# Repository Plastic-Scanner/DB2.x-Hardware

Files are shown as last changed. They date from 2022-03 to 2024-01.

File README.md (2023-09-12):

# DB2.x-Hardware

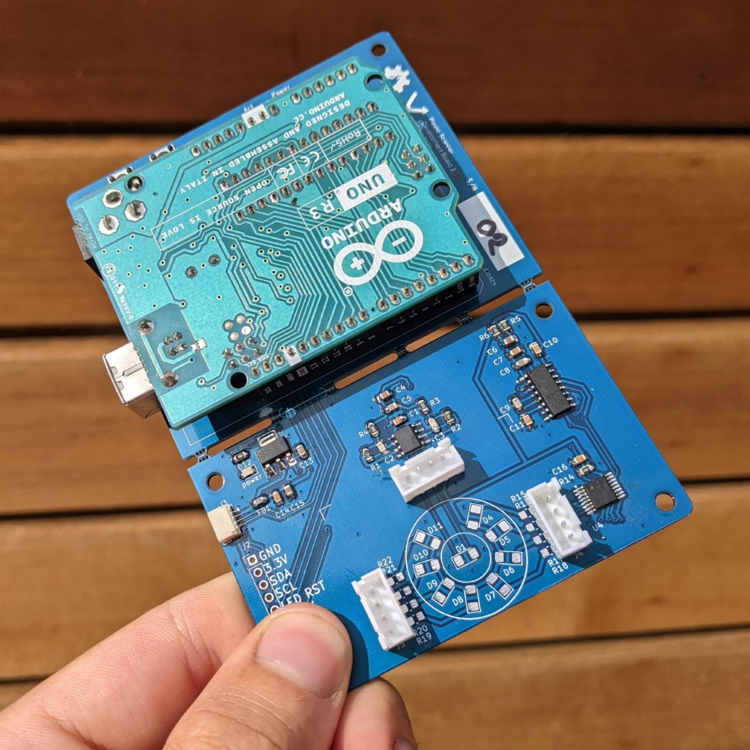
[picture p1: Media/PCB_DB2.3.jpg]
development board 2.3


>CAUTION  
This is still an early development prototype. We recommend all makers, hackers and contributors to wait until the next development board release, where we will focus on making it reproducible and invite everyone to collaborate on.  

Hi and welcome to the hardware package of the Development Board 2.x
this repository is meant to host files and have releases. 

Learn more about the development board by visiting our [documentation page](https://docs.plasticscanner.com/boards/DB2.2).  
<!-- Find the firmware for the development board [here](https://github.com/Plastic-Scanner/DB2.x-Firmware) -->

license

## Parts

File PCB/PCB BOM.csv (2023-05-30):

Id | Designator | Footprint | Quantity | Designation | Supplier and ref
1 | D5 | LED_1206_3216Metric_Pad1.42x1.75mm_HandSolder | 1 | 1050nm
2 | mouse-bite-2mm-slot,mouse-bite-2mm-slot,mouse-bite-2mm-slot,mouse-bite-2mm-slot,mouse-bite-2mm-slot,mouse-bite-2mm-slot | mouse-bite-2mm-slot | 6 | VAL**
3 | D12,D3 | LED_0805_2012Metric_Pad1.15x1.40mm_HandSolder | 2 | LED RED
4 | R15,R17,R21,R16,R19,R20,R22,R18 | R_0805_2012Metric_Pad1.20x1.40mm_HandSolder | 8 | 47
5 | D1 | D_1206_3216Metric_Pad1.42x1.75mm_HandSolder | 1 | 0090-3111-185
6 | R6,R5 | R_0805_2012Metric_Pad1.20x1.40mm_HandSolder | 2 | 51
7 | R9,R10 | R_0805_2012Metric_Pad1.20x1.40mm_HandSolder | 2 | 10k
8 | J3 | JST_SH_SM04B-SRSS-TB_1x04-1MP_P1.00mm_Horizontal | 1 | Qwiic
9 | C5,C8 | C_0805_2012Metric_Pad1.18x1.45mm_HandSolder | 2 | 100p
10 | D10 | LED_1206_3216Metric_Pad1.42x1.75mm_HandSolder | 1 | 1650nm
11 | U1 | SOIC127P599X175-8N | 1 | OPA2376AID
12 | C13 | C_0805_2012Metric_Pad1.18x1.45mm_HandSolder | 1 | 10u
13 | C10,C7,C1,C11 | C_0805_2012Metric_Pad1.18x1.45mm_HandSolder | 4 | 0.1u
14 | D9 | LED_1206_3216Metric_Pad1.42x1.75mm_HandSolder | 1 | 1550nm
15 | U2 | Nuvoton-NAU7802SGI-0-0-0 | 1 | NAU7802SGI
16 | C4 | C_0805_2012Metric_Pad1.18x1.45mm_HandSolder | 1 | 47n
17 | A1 | Arduino_UNO_R3 | 1 | Arduino_UNO_R3
18 | C16,C14 | C_0805_2012Metric_Pad1.18x1.45mm_HandSolder | 2 | 100n
19 | C6,C15 | C_0805_2012Metric_Pad1.18x1.45mm_HandSolder | 2 | 22u
20 | R4,R3 | R_0805_2012Metric_Pad1.20x1.40mm_HandSolder | 2 | 300
21 | R2,R1 | R_0805_2012Metric_Pad1.20x1.40mm_HandSolder | 2 | 240k
22 | FB1 | R_0805_2012Metric_Pad1.20x1.40mm_HandSolder | 1 | FerriteBead
23 | C9 | C_0805_2012Metric_Pad1.18x1.45mm_HandSolder | 1 | 330p
24 | D6 | LED_1206_3216Metric_Pad1.42x1.75mm_HandSolder | 1 | 1200nm
25 | J5,J1,J4 | PinSocket_1x04_P2.54mm_Vertical | 3 | Conn_01x04
26 | SW2 | SW_PUSH_6mm | 1 | TRIGGER
27 | D7 | LED_1206_3216Metric_Pad1.42x1.75mm_HandSolder | 1 | 1300nm
28 | U4 | Texas_Instruments-TLC59208FIPWR-Level_A | 1 | TLC59208FIPWR
29 | D4 | LED_1206_3216Metric_Pad1.42x1.75mm_HandSolder | 1 | 940nm
30 | R7,R11,R8 | R_0805_2012Metric_Pad1.20x1.40mm_HandSolder | 3 | 100
31 | J2 | PinHeader_1x08_P2.54mm_Vertical | 1 | Conn_01x08
32 | D11 | LED_1206_3216Metric_Pad1.42x1.75mm_HandSolder | 1 | 1720nm
33 | R14 | R_0805_2012Metric_Pad1.20x1.40mm_HandSolder | 1 | 1k
34 | U3 | SOT-223-3_TabPin2 | 1 | AMS1117-3.3
35 | D8 | LED_1206_3216Metric_Pad1.42x1.75mm_HandSolder | 1 | 1460nm
36 | C2,C3 | C_0805_2012Metric_Pad1.18x1.45mm_HandSolder | 2 | 51p
37 | D2 | LED_0805_2012Metric_Pad1.15x1.40mm_HandSolder | 1 | LED BLUE
38 | SW1 | SW_PUSH_6mm | 1 | MCU_RESET

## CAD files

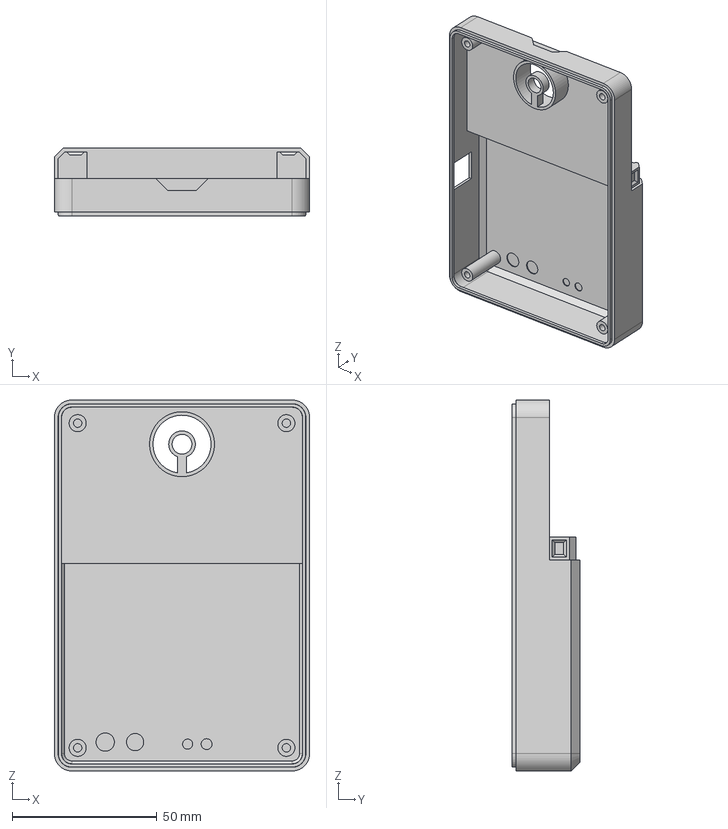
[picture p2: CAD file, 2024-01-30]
CAD/3D_print_files/DB_enclosure_top.step
88.1 x 23.3 x 128.0 mm

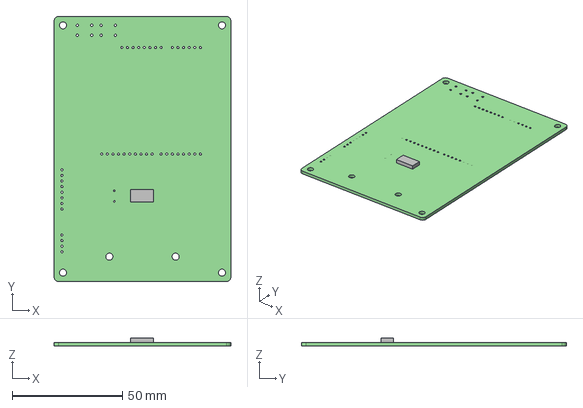
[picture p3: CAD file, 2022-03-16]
CAD/PCB KiCad.step
80.0 x 120.0 x 3.60 mm
PCB KiCad PCB

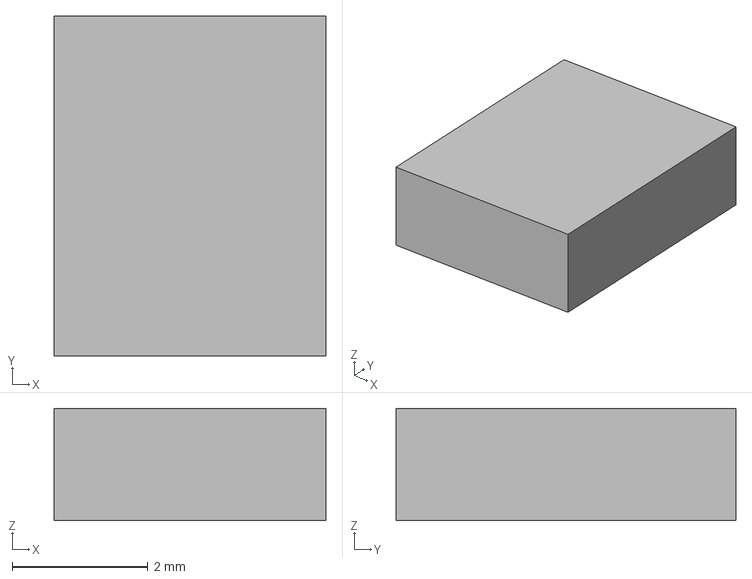
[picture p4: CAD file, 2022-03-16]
PCB/PCB KiCad/symbol_and_footprints/IC_Analog Devices_ADR03ARZ-REEL7/eec.models/Analog_Devices_-_ADR03ARZ-REEL7.step
4.00 x 5.00 x 1.65 mm

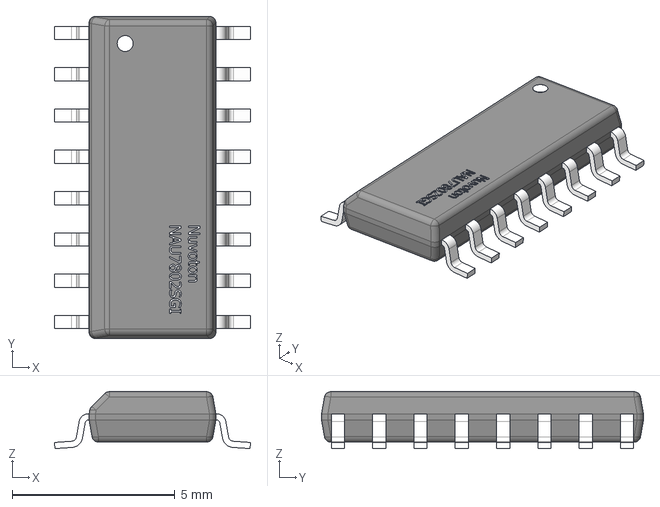
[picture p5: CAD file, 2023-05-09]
PCB/PCB KiCad/symbol_and_footprints/IC_Nuvoton_NAU7802SGI/eec.models/Nuvoton_-_NAU7802SGI.step
6.03 x 9.90 x 1.76 mm

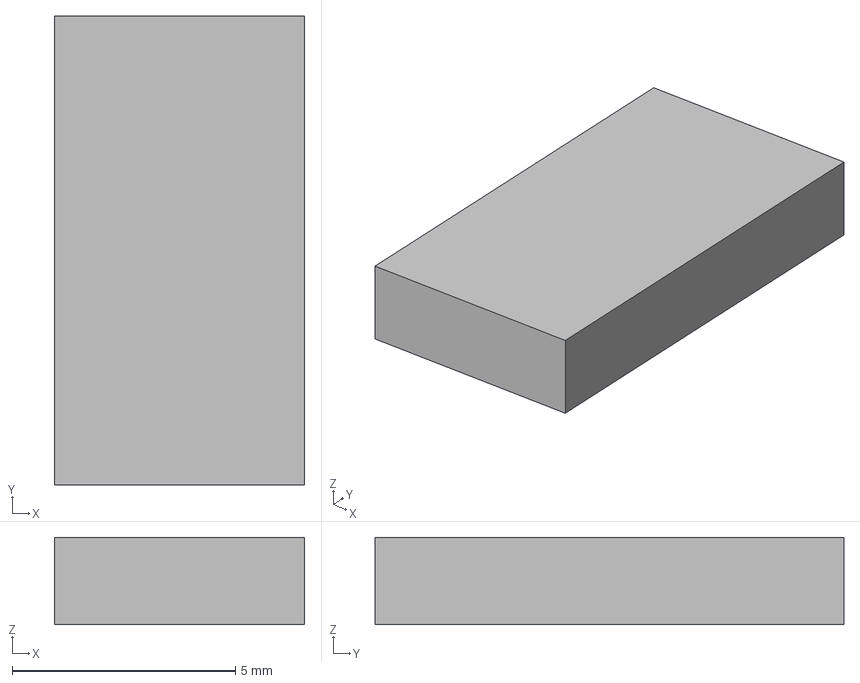
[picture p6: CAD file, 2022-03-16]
PCB/PCB KiCad/symbol_and_footprints/IC_Texas Instruments_ADS1256IDBT/eec.models/Texas_Instruments_-_ADS1256IDBT.step
5.60 x 10.5 x 1.95 mm

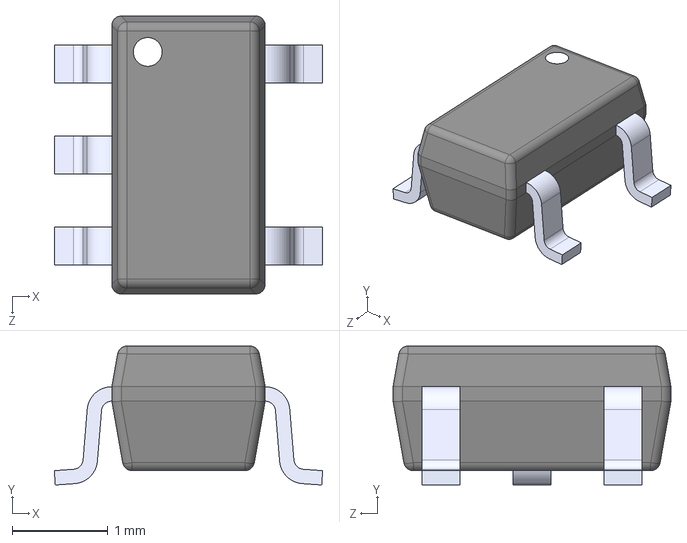
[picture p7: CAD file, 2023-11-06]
PCB/PCB KiCad/symbol_and_footprints/LP5951MFX-1.8_NOPB/LP5951MFX-1.8_NOPB.step
2.80 x 1.45 x 2.90 mm

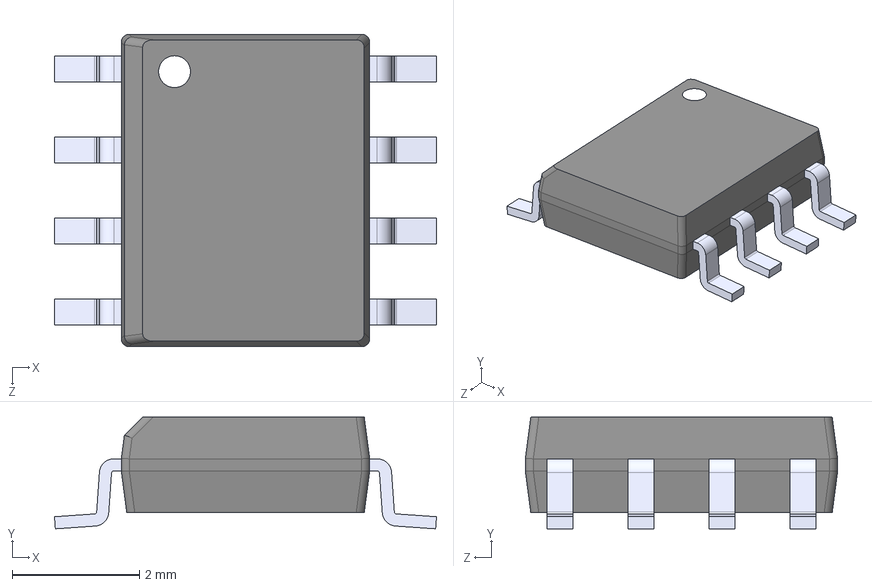
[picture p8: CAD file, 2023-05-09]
PCB/PCB KiCad/symbol_and_footprints/OPA2376AID/OPA2376AID.step
5.99 x 1.75 x 4.90 mm

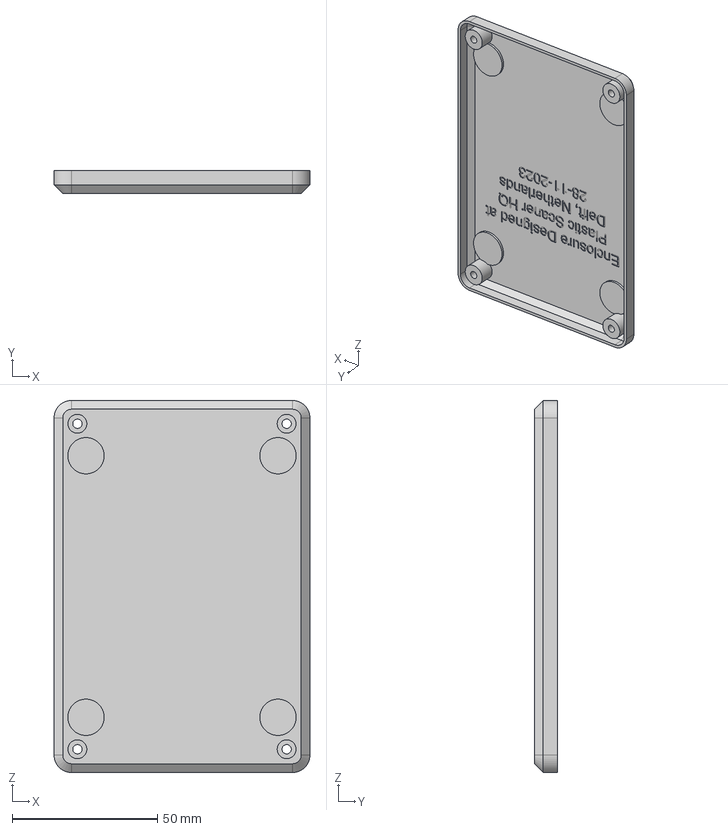
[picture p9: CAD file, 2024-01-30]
CAD/3D_print_files/DB_enclosure_bottom.step
88.1 x 8.00 x 128.0 mm

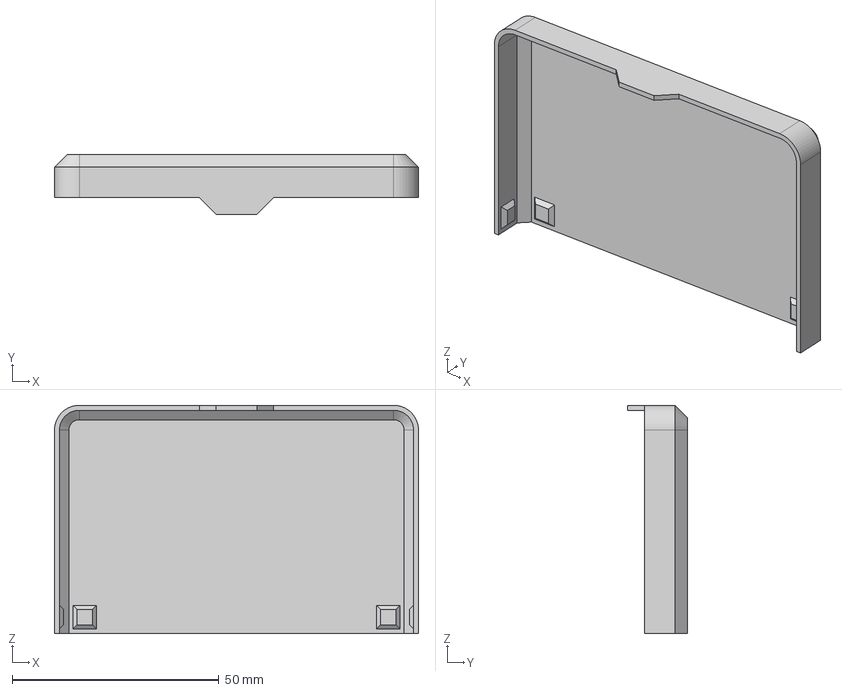
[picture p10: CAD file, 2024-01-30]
CAD/3D_print_files/DB_enclosure_top_cover.step
88.1 x 14.4 x 55.3 mm

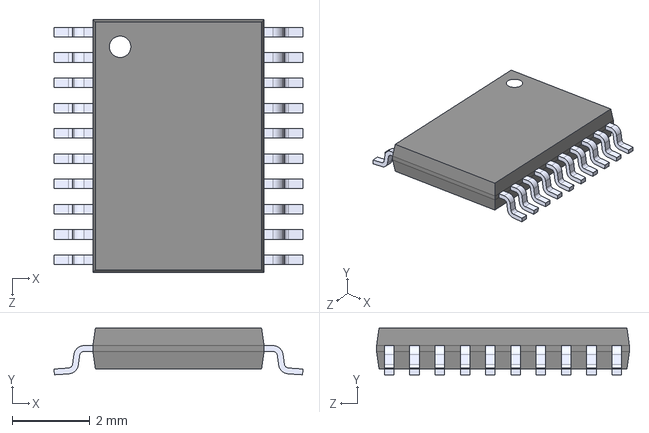
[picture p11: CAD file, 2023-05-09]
PCB/PCB KiCad/symbol_and_footprints/TLC59108IPWR.step
6.40 x 1.20 x 6.50 mm

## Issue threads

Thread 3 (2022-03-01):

Fix the indicator for 2.5v reference voltage

jurc192, 2022-03-01:
LED3 (indicator for 2.5v reference) is breaking the reference voltage because it is drawing too much current

Closed 2022-03-16.

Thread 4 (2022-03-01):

Use different pin for nRESET of the TLC59208

jurc192, 2022-03-01:
Pin D0 is currently used for the reset of the LED driver, but the same pin is used by UART and randomly resets the LED driver during serial communication.
Current workaround: desolder r24 and connect a wire from pin D2 to the led drive side of r24 pad.

Closed 2022-03-16.

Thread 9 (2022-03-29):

SIlkscreen label "trigger" and "reset" are swapped

Jerzeek, 2022-03-29:

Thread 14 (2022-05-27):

Proper Resistor Value for IR LED

wtwver, 2022-05-27:
Hi,

I found the Resistor Value for IR LED is different between the 2.1 release and latest commit.
Would you mind to create a new release like 2.1.1 if the values change is crucial ?

Also, which values should be followed when creating the PCB ?

Thanks

Jerzeek, 2023-02-27:
fixed!

Closed 2023-02-27.

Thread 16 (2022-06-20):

Propose PCB with color sensor AS7341

Jerzeek, 2022-06-20:
We did not test it much, but we think it can be a benefit to add the color sensor on the board. The KiCAD files are online, they just need the footprint of the AS7341 component, the required caps/resistors, and routing for the I2C lines.

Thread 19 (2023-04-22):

TLC59208 LED driver not available anymore

Jerzeek, 2023-04-22:
Originally designed the DB board with the TLC59208 I2C LED driver.
A drop-in replacement can be the [PCA9551](https://www.digikey.nl/nl/products/detail/nxp-usa-inc/PCA9551PW-118/5221884)
but requires other firmware. and it can only output a maximum of 25mA

Another option can be the [TLC59108](https://www.lcsc.com/product-detail/_Texas-Instruments-_C2678527.html) LCSC has a couple of 100 available and can do 120mA per LED

Both options will be tested

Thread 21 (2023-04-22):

differential pair between diode and opamp @jitter feedback

Jerzeek, 2023-04-22:

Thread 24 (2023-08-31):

New bill of material with correct parts number

abdulazeeznaji, 2023-08-31:
No parts number is inlcuded only description of the part

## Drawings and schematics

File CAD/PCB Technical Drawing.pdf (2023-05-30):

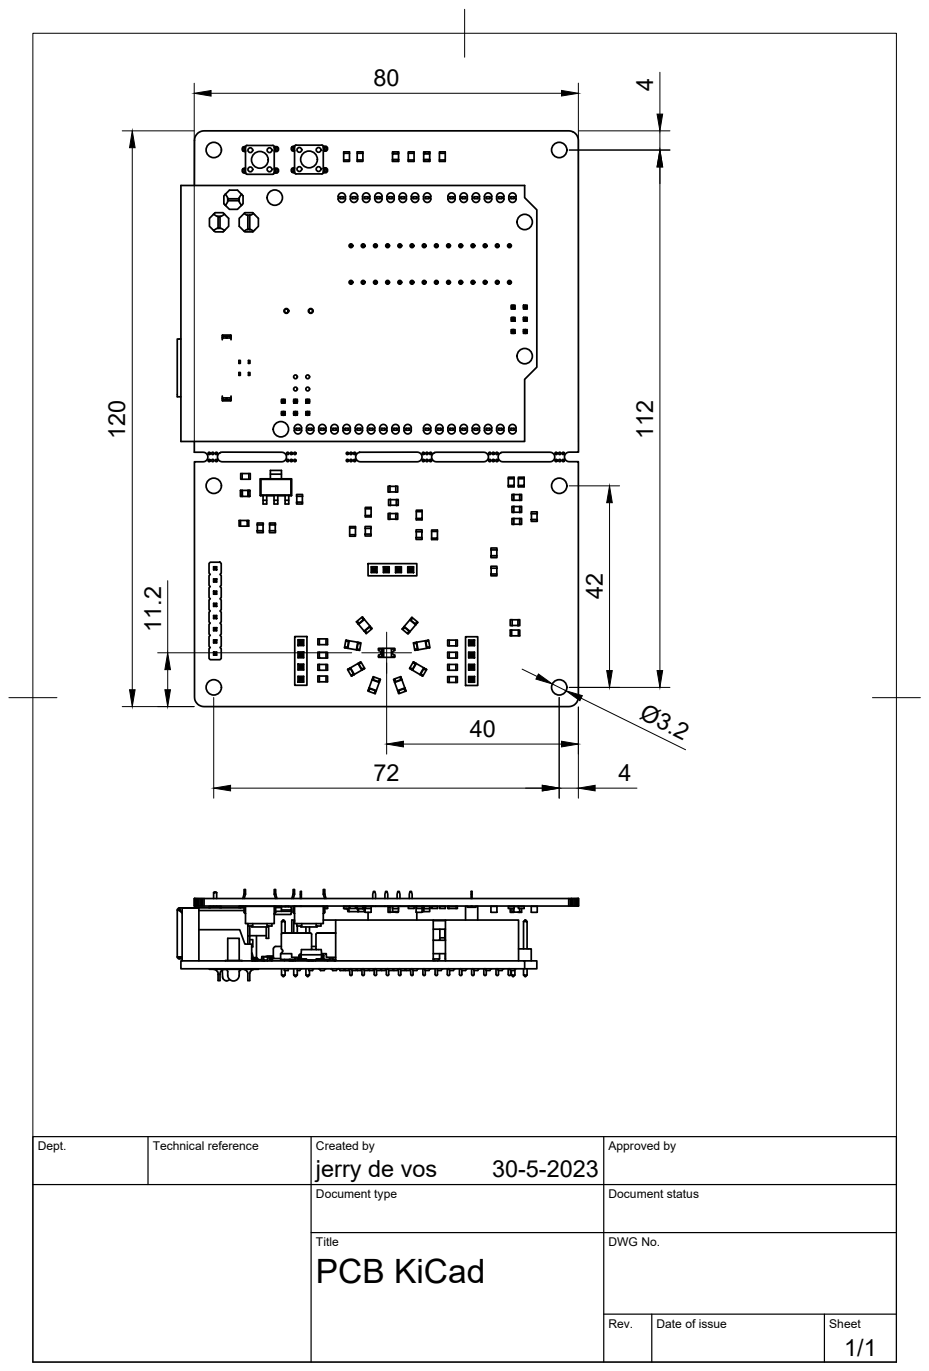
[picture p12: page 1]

jerry de vos 120

Dept. | Technical reference | Created by 30-5-2023 | Approved by

Document type | Document status

Title PCB KiCad | DWG No.

Rev. | Date of issue | Sheet 1/1

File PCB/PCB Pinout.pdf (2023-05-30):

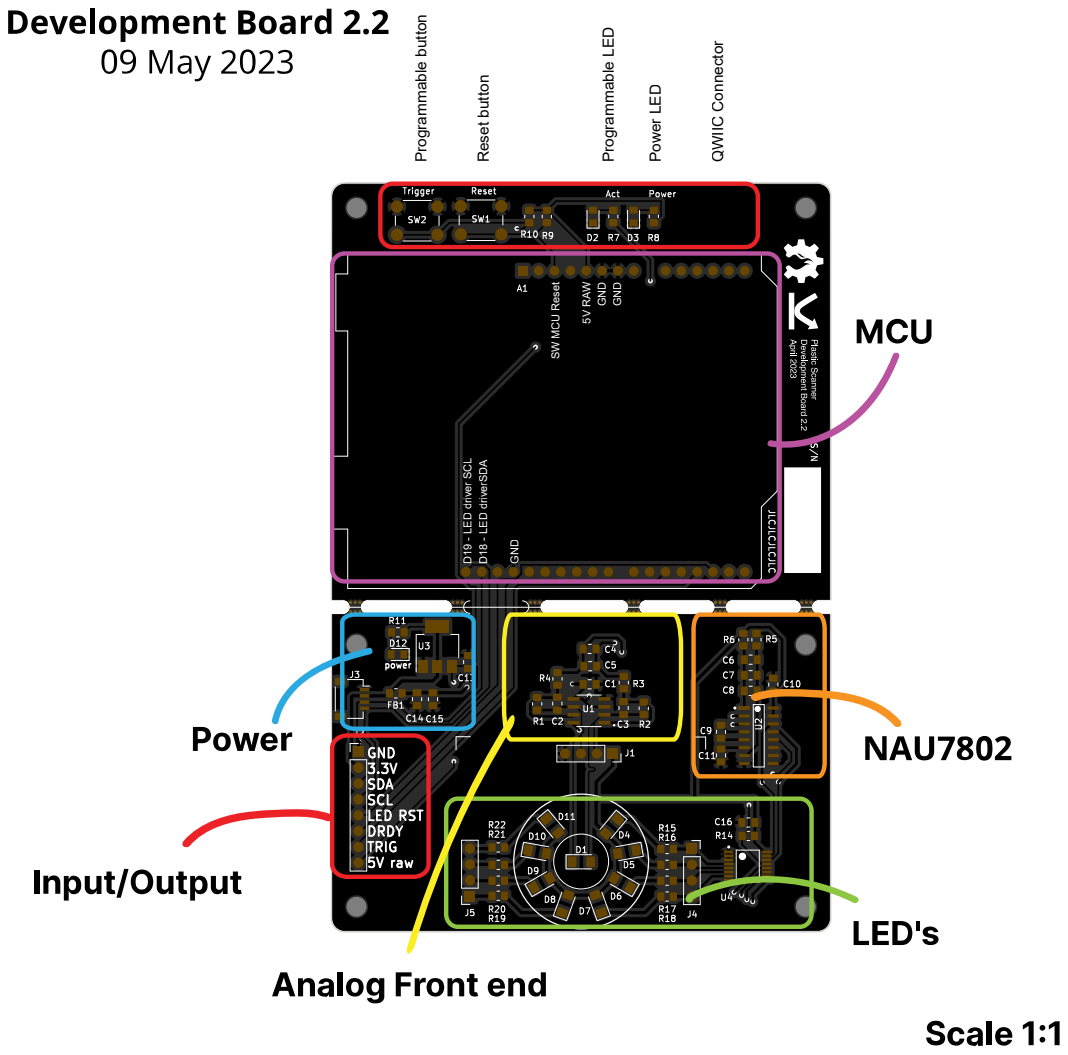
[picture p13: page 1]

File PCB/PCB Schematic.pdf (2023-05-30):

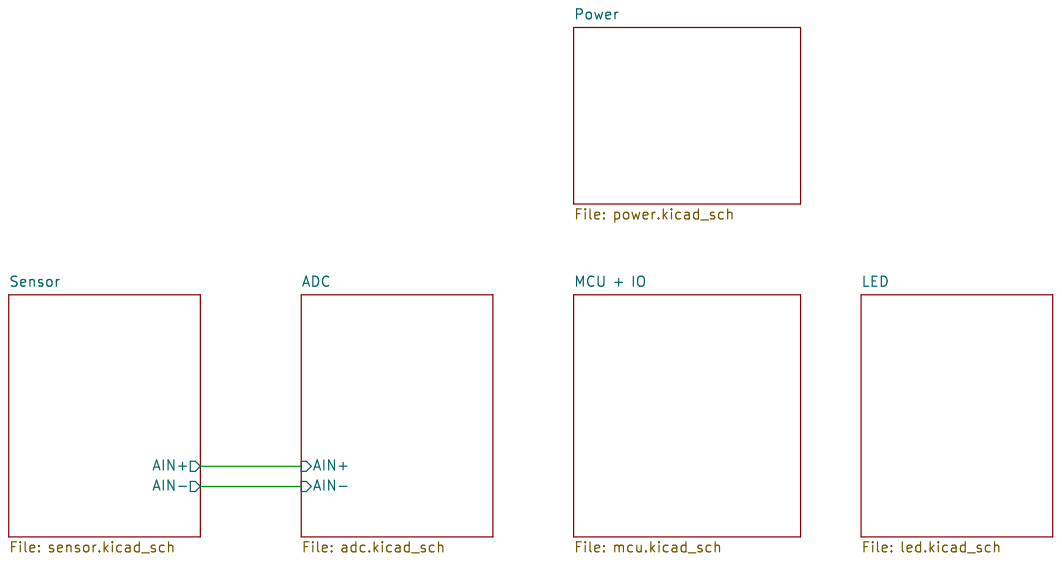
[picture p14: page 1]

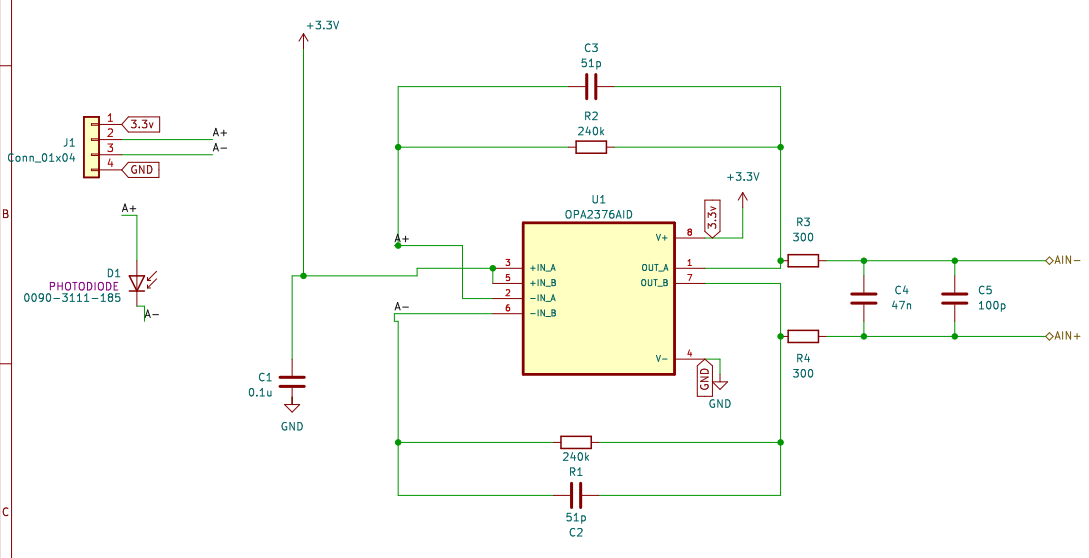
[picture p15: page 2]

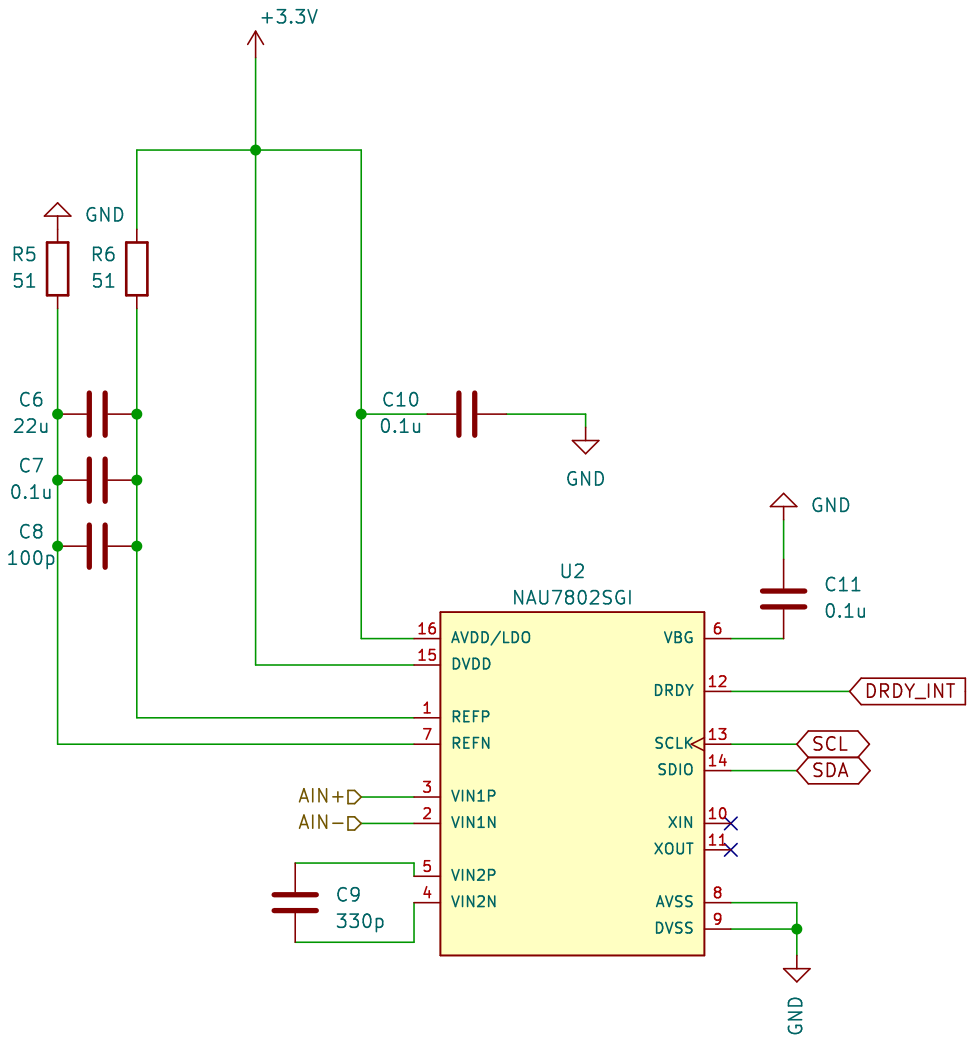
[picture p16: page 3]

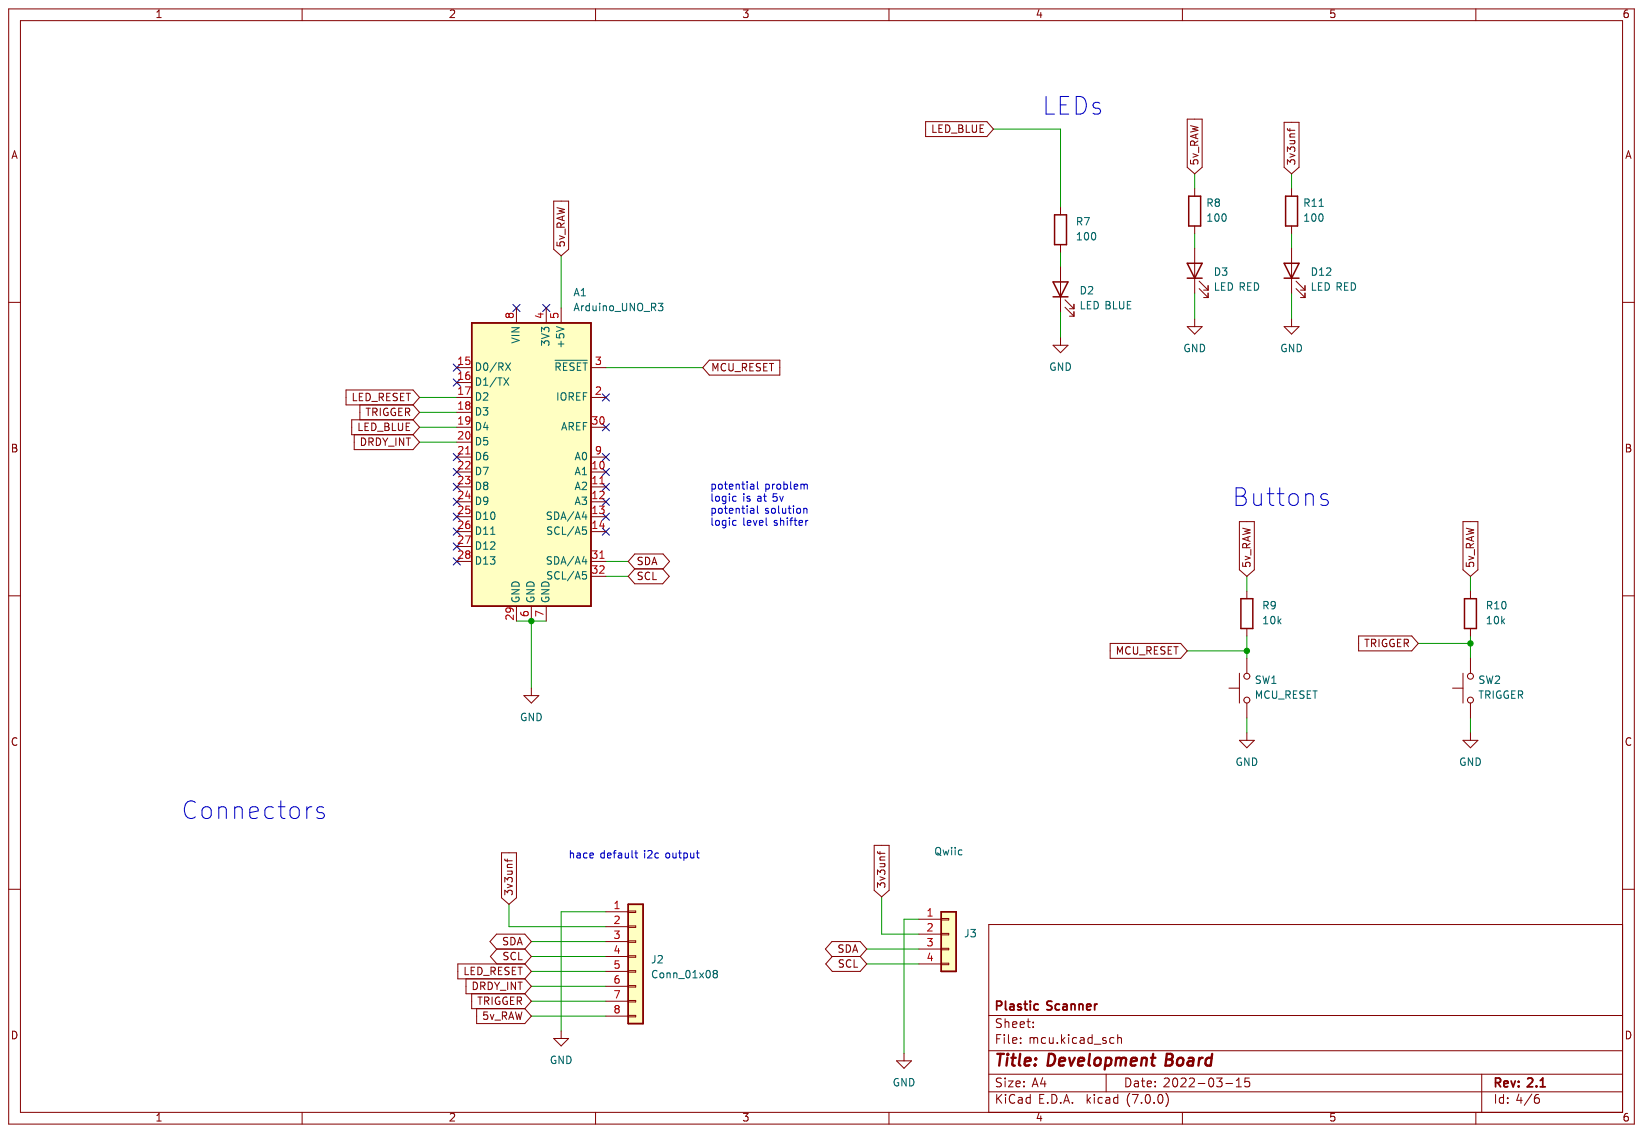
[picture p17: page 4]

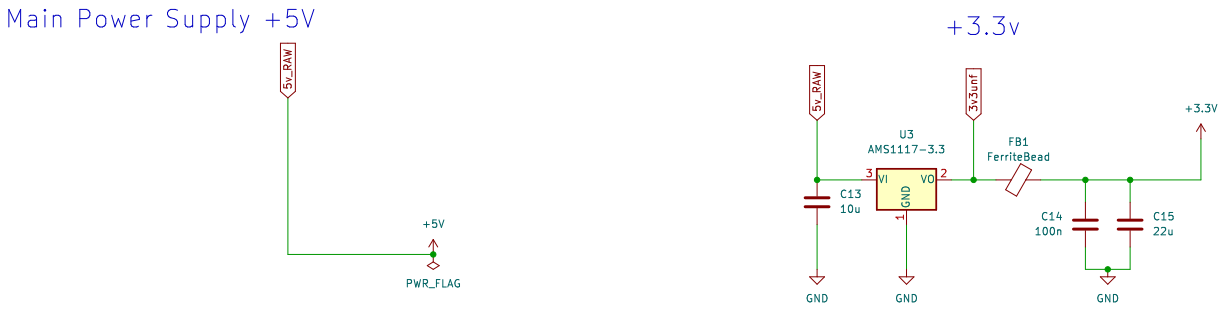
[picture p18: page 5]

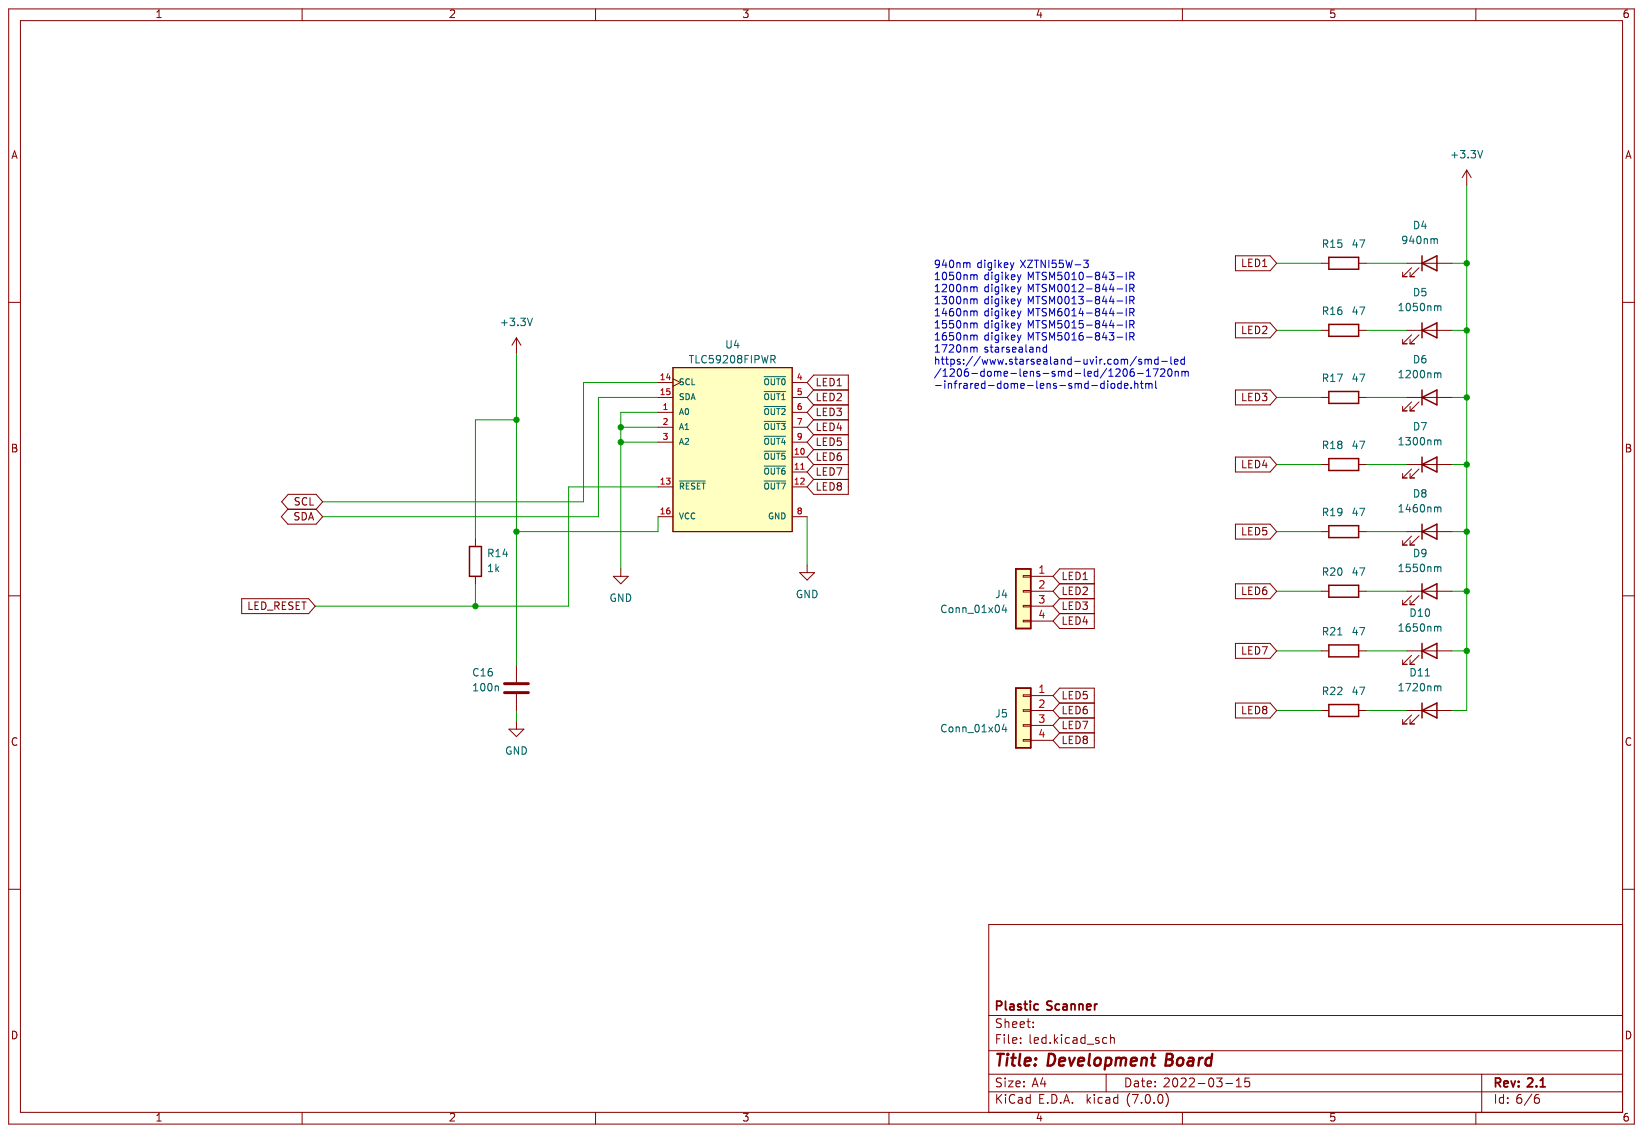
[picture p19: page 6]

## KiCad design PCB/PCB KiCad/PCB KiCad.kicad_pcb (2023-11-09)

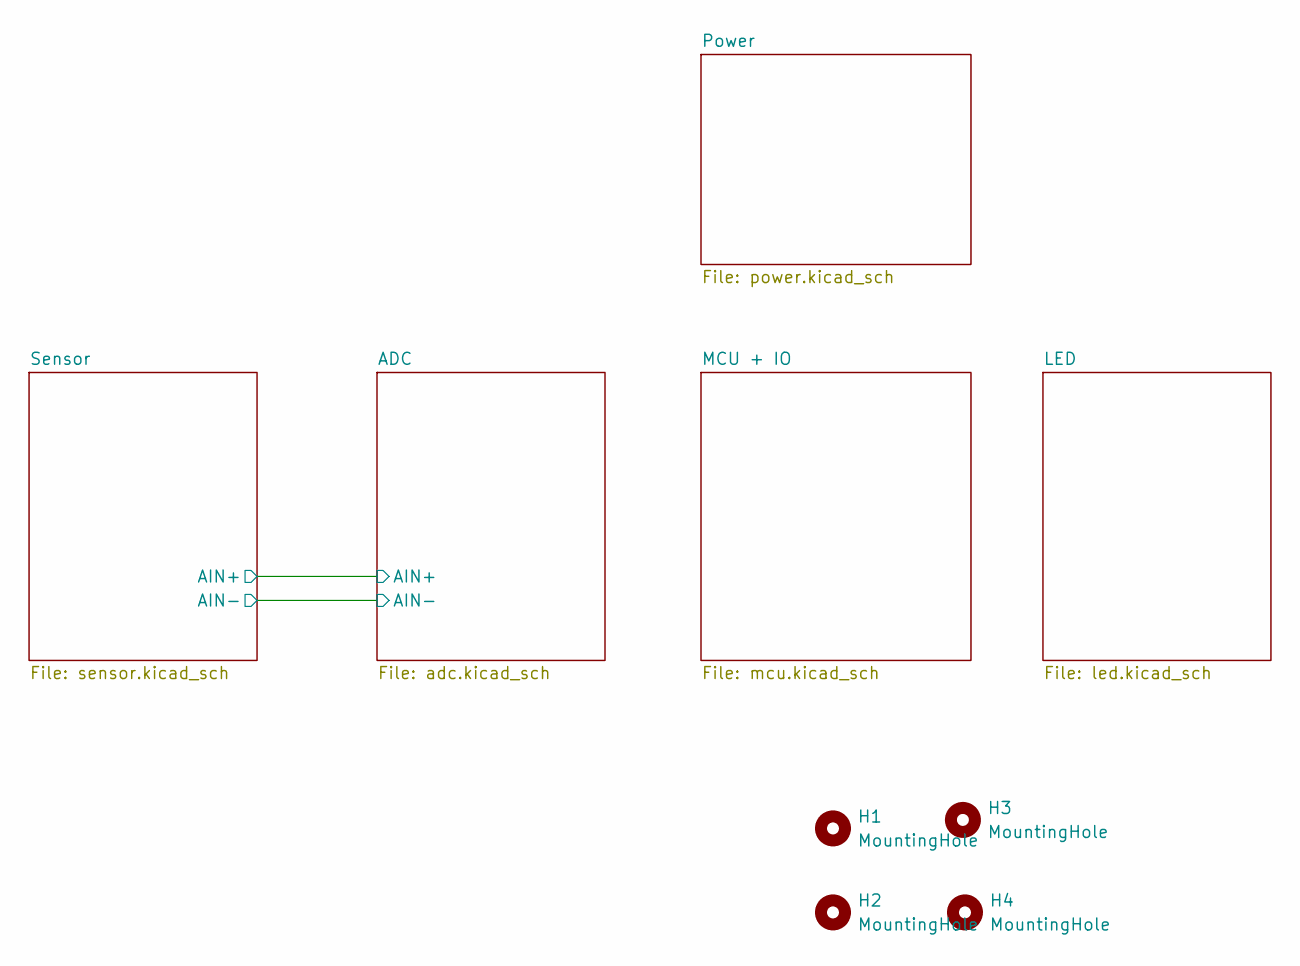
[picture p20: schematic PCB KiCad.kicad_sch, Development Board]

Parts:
H1, H2, H3, H4: MountingHole; MountingHole_3.2mm_M3

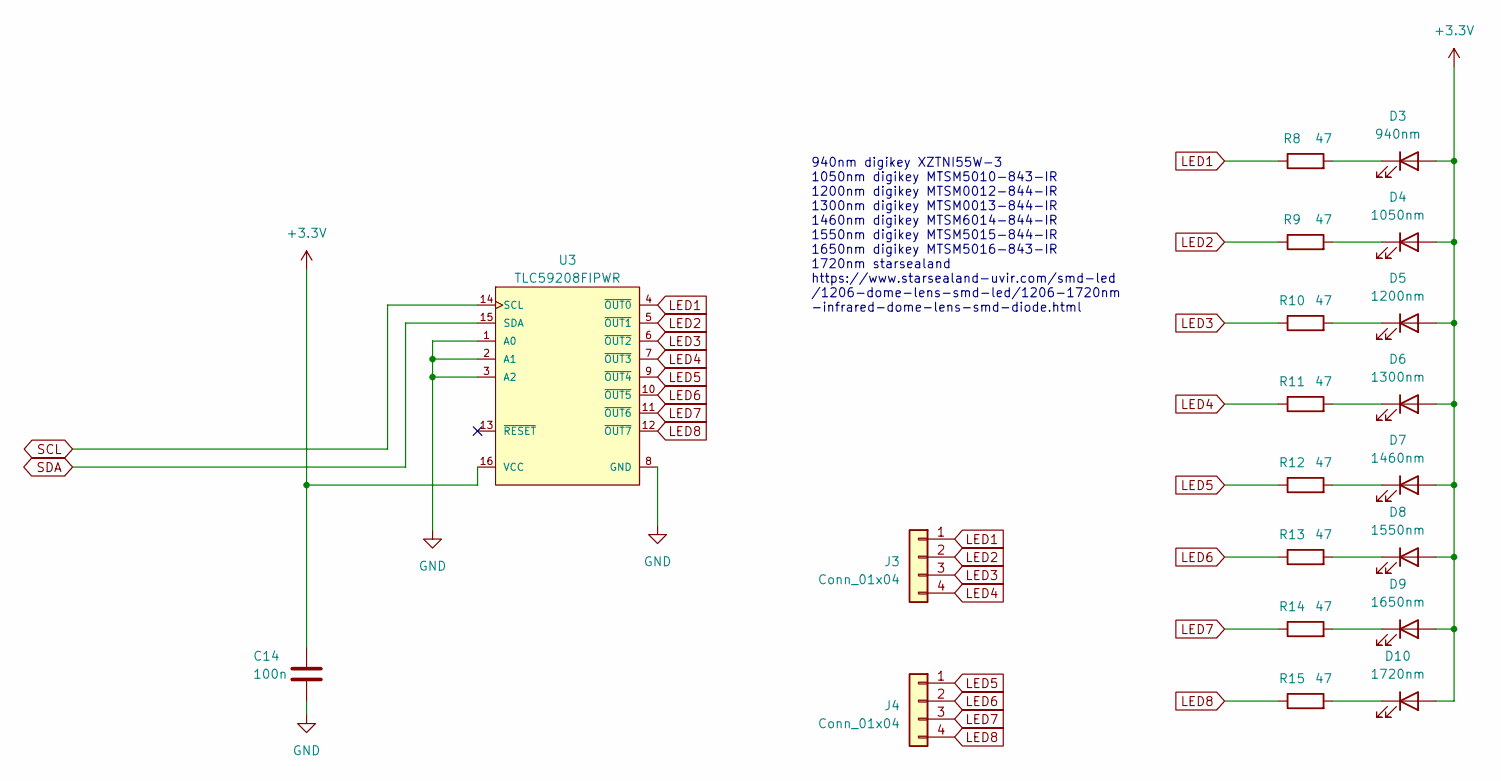
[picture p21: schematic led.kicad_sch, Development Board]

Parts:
C14: 100n; C_0805_2012Metric_Pad1.18x1.45mm_HandSolder
D3: 940nm; LED_1206_3216Metric_Pad1.42x1.75mm_HandSolder
D4: 1050nm; LED_1206_3216Metric_Pad1.42x1.75mm_HandSolder
D5: 1200nm; LED_1206_3216Metric_Pad1.42x1.75mm_HandSolder
D6: 1300nm; LED_1206_3216Metric_Pad1.42x1.75mm_HandSolder
D7: 1460nm; LED_1206_3216Metric_Pad1.42x1.75mm_HandSolder
D8: 1550nm; LED_1206_3216Metric_Pad1.42x1.75mm_HandSolder
D9: 1650nm; LED_1206_3216Metric_Pad1.42x1.75mm_HandSolder
D10: 1720nm; LED_1206_3216Metric_Pad1.42x1.75mm_HandSolder
J3, J4: Conn_01x04; PinSocket_1x04_P2.54mm_Vertical
R8, R9, R10, R11, R12, R13, R14, R15: 47; R_0805_2012Metric_Pad1.20x1.40mm_HandSolder
U3: TLC59208FIPWR; Texas_Instruments-TLC59208FIPWR-Level_A

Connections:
3.3v: C14.1, D3.2 (A), D4.2 (A), D5.2 (A), D6.2 (A), D7.2 (A), D8.2 (A), D9.2 (A), D10.2 (A), U3.16 (VCC); also elsewhere on the board
GND: C14.2, U3.1 (A0), U3.2 (A1), U3.3 (A2), U3.8 (GND); also elsewhere on the board
LED1: J3.1, R8.1, U3.4 (~OUT0)
LED2: J3.2, R9.1, U3.5 (~OUT1)
LED3: J3.3, R10.1, U3.6 (~OUT2)
LED4: J3.4, R11.1, U3.7 (~OUT3)
LED5: J4.1, R12.1, U3.9 (~OUT4); also elsewhere on the board
LED6: J4.2, R13.1, U3.10 (~OUT5); also elsewhere on the board
LED7: J4.3, R14.1, U3.11 (~OUT6); also elsewhere on the board
LED8: J4.4, R15.1, U3.12 (~OUT7); also elsewhere on the board
unnamed: D3.1 (K), R8.2
unnamed: D4.1 (K), R9.2
unnamed: D5.1 (K), R10.2
unnamed: D6.1 (K), R11.2
unnamed: D7.1 (K), R12.2
unnamed: D8.1 (K), R13.2
unnamed: D9.1 (K), R14.2
unnamed: D10.1 (K), R15.2
SCL: U3.14 (SCL); also elsewhere on the board
SDA: U3.15 (SDA); also elsewhere on the board

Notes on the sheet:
940nm digikey XZTNI55W-3 1050nm digikey MTSM5010-843-IR 1200nm digikey MTSM0012-844-IR 1300nm digikey MTSM0013-844-IR 1460nm digikey MTSM6014-844-IR 1550nm digikey MTSM5015-844-IR 1650nm digikey MTSM5016-843-IR 1720nm starsealand https://www.starsealand-uvir.com/smd-led /1206-dome-lens-smd-led/1206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

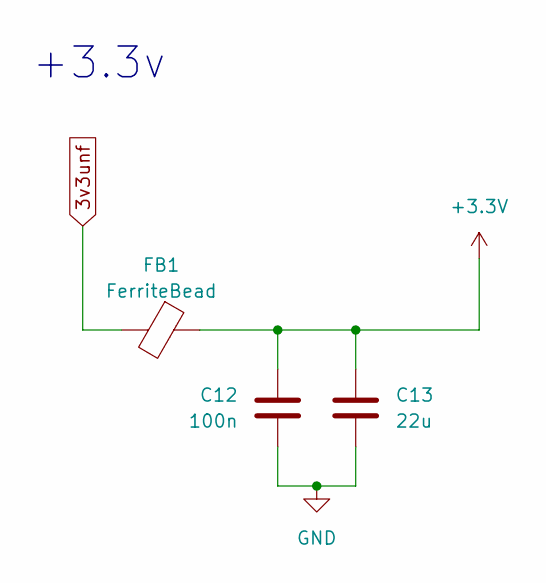
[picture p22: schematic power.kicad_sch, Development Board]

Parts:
C12: 100n; C_0805_2012Metric_Pad1.18x1.45mm_HandSolder
C13: 22u; C_0805_2012Metric_Pad1.18x1.45mm_HandSolder
FB1: FerriteBead; R_0805_2012Metric_Pad1.20x1.40mm_HandSolder

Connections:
3.3v: C12.2, C13.1, FB1.1; also elsewhere on the board
3v3unf: FB1.2; also elsewhere on the board
GND: C12.1, C13.2; also elsewhere on the board

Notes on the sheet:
+3.3v

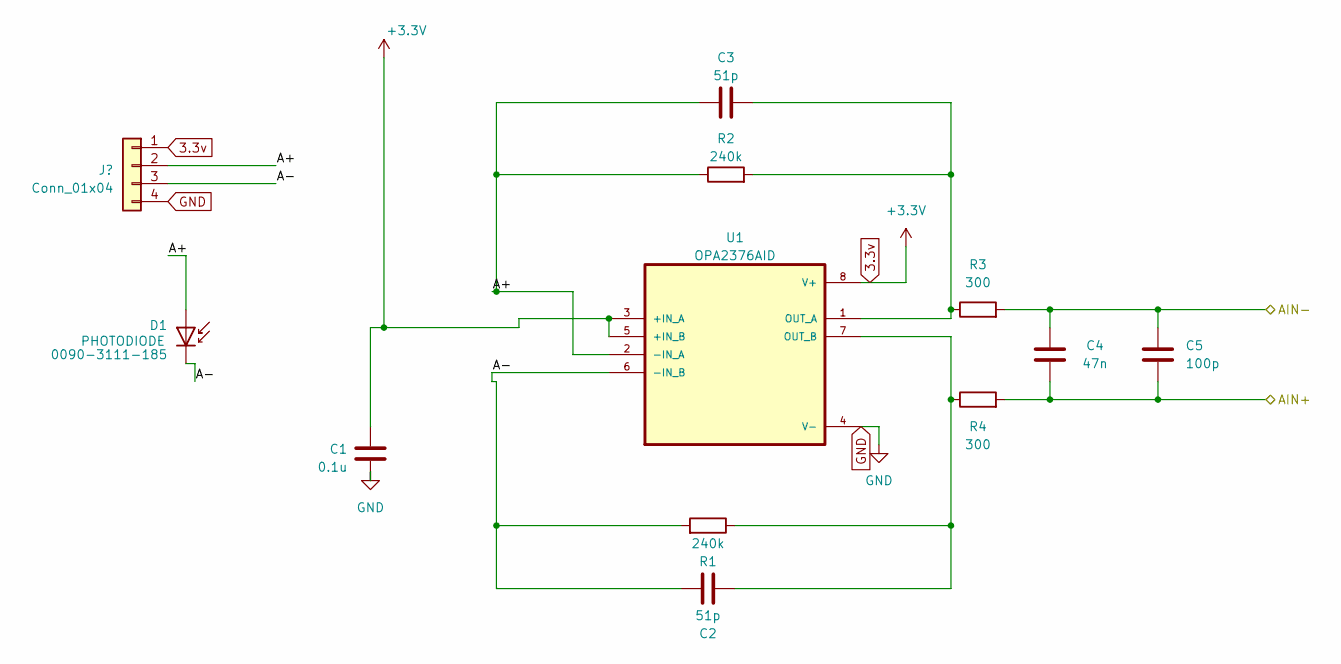
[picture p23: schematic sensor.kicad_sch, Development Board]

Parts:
C1: 0.1u; C_0805_2012Metric_Pad1.18x1.45mm_HandSolder
C2, C3: 51p; C_0805_2012Metric_Pad1.18x1.45mm_HandSolder
C4: 47n; C_0805_2012Metric_Pad1.18x1.45mm_HandSolder
C5: 100p; C_0805_2012Metric_Pad1.18x1.45mm_HandSolder
D1: 0090-3111-185; D_A-405_P2.54mm_Vertical_KathodeUp
J1: Conn_01x04; PinSocket_1x04_P2.54mm_Vertical
R1, R2: 240k; R_0805_2012Metric_Pad1.20x1.40mm_HandSolder
R3, R4: 300; R_0805_2012Metric_Pad1.20x1.40mm_HandSolder
U1: OPA2376AID; SOIC127P599X175-8N

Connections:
3.3v: C1.2, J1.1, U1.3 (+IN_A), U1.5 (+IN_B), U1.8 (V+); also elsewhere on the board
/ADC/AIN+: C4.1, C5.2, R4.2; also elsewhere on the board
/ADC/AIN-: C4.2, C5.1, R3.2; also elsewhere on the board
/Sensor/A+: C3.1, D1.2 (A), J1.2, R2.1, U1.2 (-IN_A)
/Sensor/A-: C2.1, D1.1 (K), J1.3, R1.2, U1.6 (-IN_B)
GND: C1.1, J1.4, U1.4 (V-); also elsewhere on the board
unnamed: C3.2, R2.2, R3.1, U1.1 (OUT_A)
unnamed: C2.2, R1.1, R4.1, U1.7 (OUT_B)

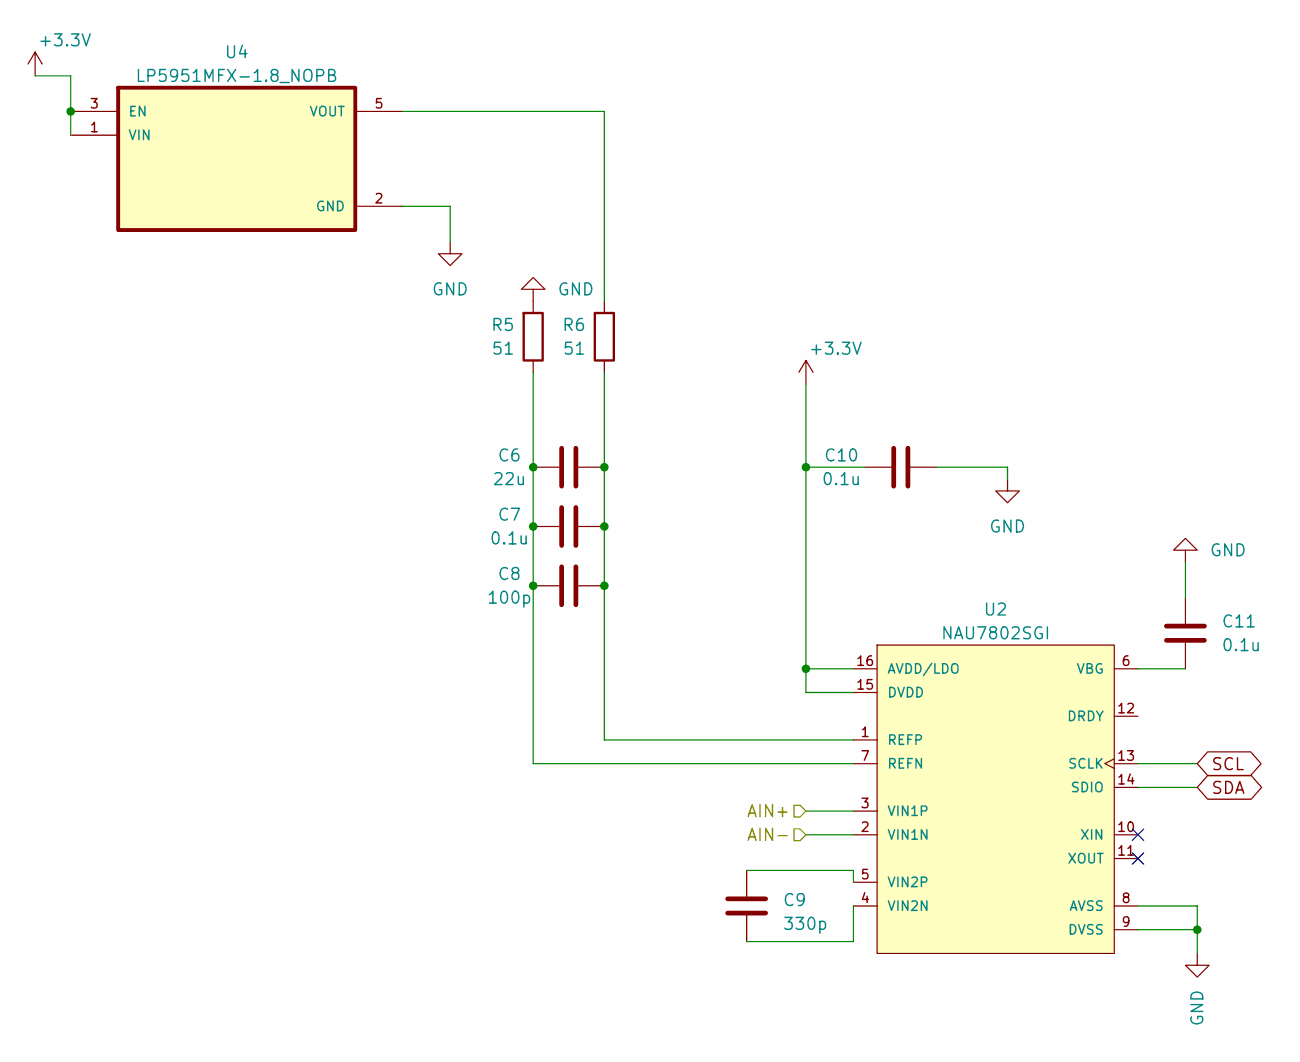
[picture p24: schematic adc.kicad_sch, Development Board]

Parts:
C6: 22u; C_0805_2012Metric_Pad1.18x1.45mm_HandSolder
C7, C10, C11: 0.1u; C_0805_2012Metric_Pad1.18x1.45mm_HandSolder
C8: 100p; C_0805_2012Metric_Pad1.18x1.45mm_HandSolder
C9: 330p; C_0805_2012Metric_Pad1.18x1.45mm_HandSolder
R5, R6: 51; R_0805_2012Metric_Pad1.20x1.40mm_HandSolder
U2: NAU7802SGI; Nuvoton-NAU7802SGI-0-0-0; digikey description IC ADC 24BIT I2C/SRL 16-SOP
U4: LP5951MFX-1.8_NOPB; SOT95P280X145-5N

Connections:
3.3v: C10.1, U2.15 (DVDD), U2.16 (AVDD/LDO), U4.1 (VIN), U4.3 (EN); also elsewhere on the board
/ADC/AIN+: U2.3 (VIN1P); also elsewhere on the board
/ADC/AIN-: U2.2 (VIN1N); also elsewhere on the board
GND: C10.2, C11.1, R5.2, U2.8 (AVSS), U2.9 (DVSS), U4.2 (GND); also elsewhere on the board
unnamed: C6.1, C7.1, C8.1, R5.1, U2.7 (REFN)
unnamed: C6.2, C7.2, C8.2, R6.1, U2.1 (REFP)
unnamed: C11.2, U2.6 (VBG)
unnamed: C9.2, U2.4 (VIN2N)
unnamed: C9.1, U2.5 (VIN2P)
unnamed: R6.2, U4.5 (VOUT)
SCL: U2.13 (SCLK); also elsewhere on the board
SDA: U2.14 (SDIO); also elsewhere on the board

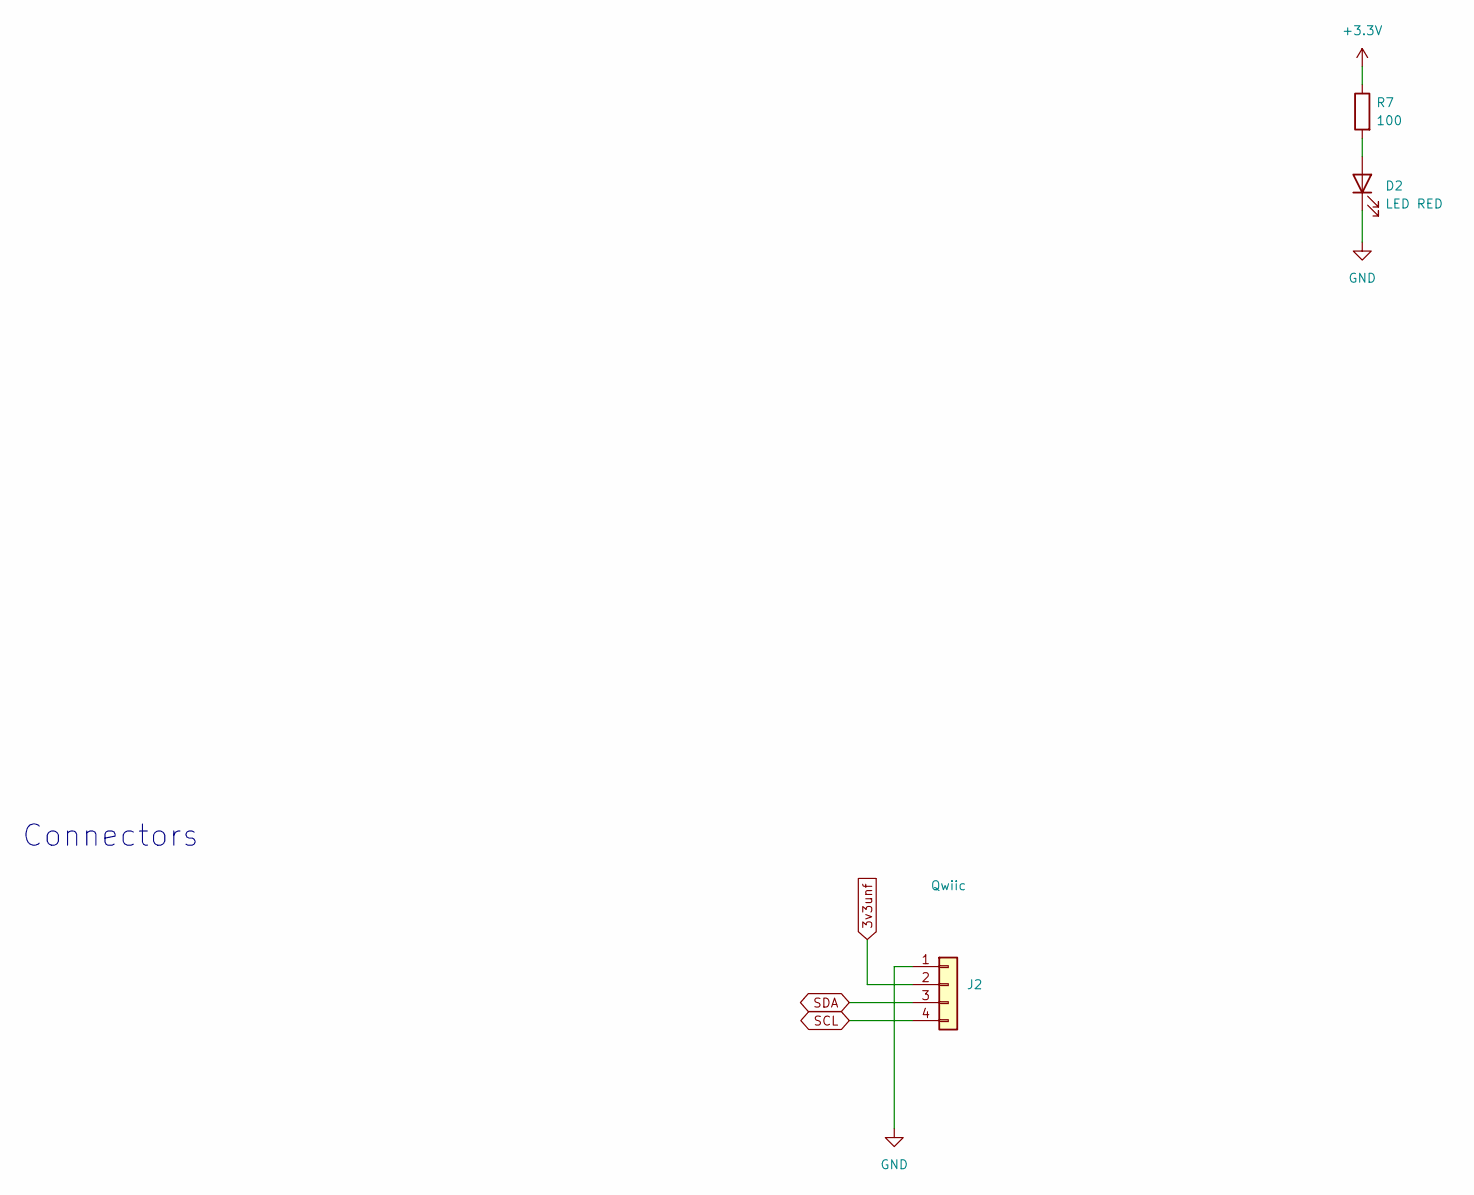
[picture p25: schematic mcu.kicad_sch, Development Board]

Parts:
D2: LED RED; LED_0805_2012Metric_Pad1.15x1.40mm_HandSolder
J2: Qwiic; JST_SH_SM04B-SRSS-TB_1x04-1MP_P1.00mm_Horizontal
R7: 100; R_0805_2012Metric_Pad1.20x1.40mm_HandSolder

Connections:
3.3v: R7.1; also elsewhere on the board
3v3unf: J2.2; also elsewhere on the board
GND: D2.1 (K), J2.1; also elsewhere on the board
unnamed: D2.2 (A), R7.2
SCL: J2.4; also elsewhere on the board
SDA: J2.3; also elsewhere on the board

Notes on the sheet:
Connectors

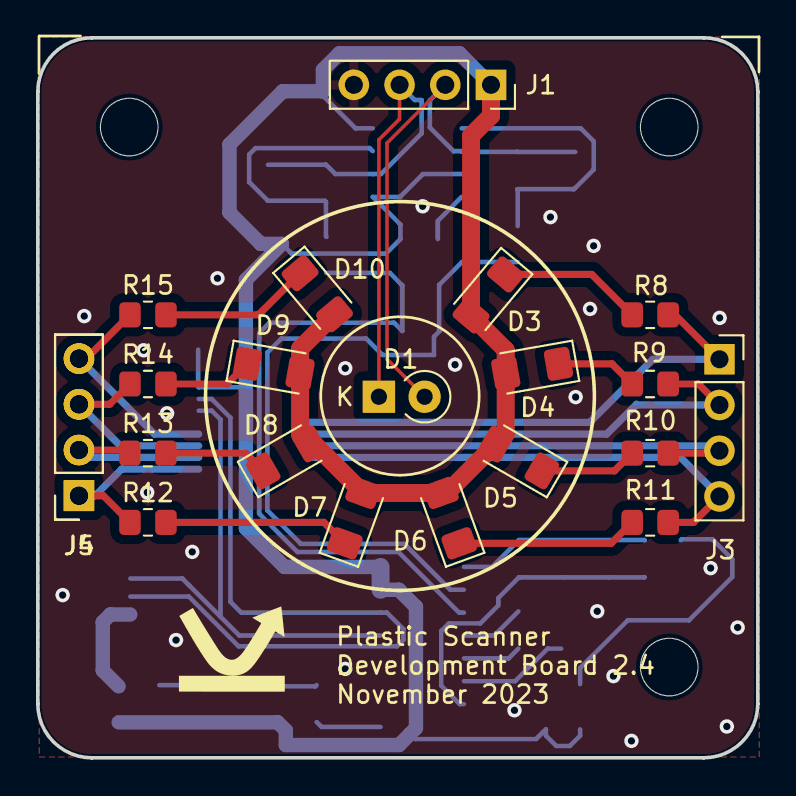
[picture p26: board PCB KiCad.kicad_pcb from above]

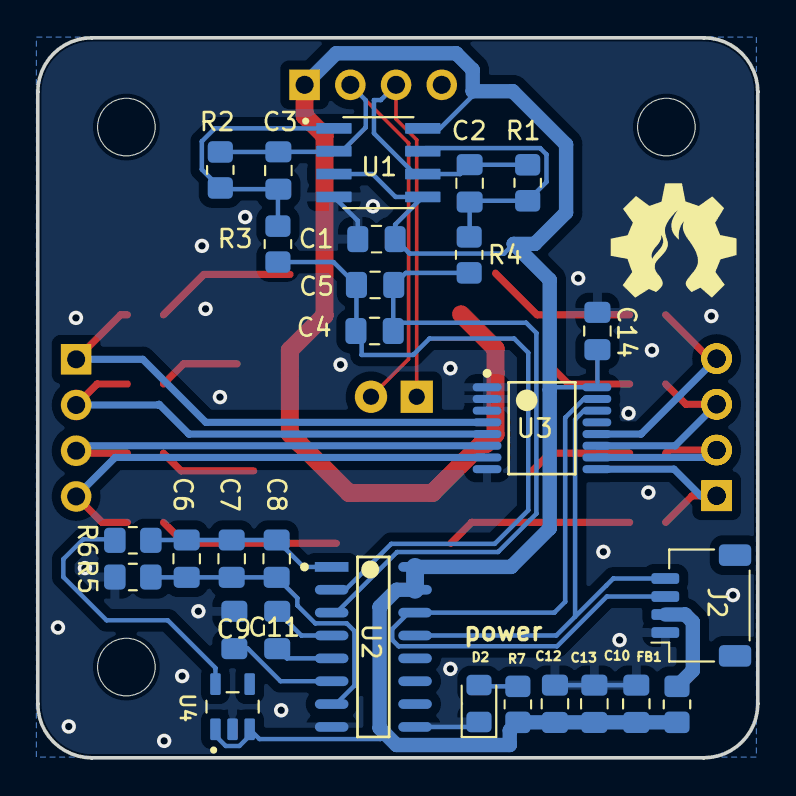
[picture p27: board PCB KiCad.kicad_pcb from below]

Board: 2 copper layers, 40.0 x 40.0 mm, 52 parts (28 on the bottom side), 34 nets.

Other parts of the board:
J5: Conn_01x04; PinSocket_1x04_P2.54mm_Vertical

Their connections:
LED5: J5.1; also elsewhere on the board
LED6: J5.2; also elsewhere on the board
LED7: J5.3; also elsewhere on the board
LED8: J5.4; also elsewhere on the board

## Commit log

2022-02-17 Initial collection of information
    [PCB BOM.csv, PCB Front view.dxf]
2022-03-07 Basic KiCad structure with gitignore file
    [PCB KiCad.kicad_pcb, PCB KiCad.kicad_sch, adc.kicad_sch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]
2022-03-07 draw schematic for 60%
    [Analog_Devices_-_ADR03ARZ-REEL7.step, PCB KiCad.kicad_sch, Texas_Instruments_-_ADS1256IDBT.step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]
2022-03-09 Add buttons: MCU RESET, TRIGGER
    [PCB KiCad.kicad_sch, adc.kicad_sch, io.kicad_sch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]
2022-03-09 Ignore autosaved files, cleanup MCU schematics
    [mcu.kicad_sch, sensor.kicad_sch]
2022-03-09 first check + add connectors
    [PCB KiCad.kicad_sch, adc.kicad_sch, led.kicad_sch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]
2022-03-09 ERC: add power flags to satisfy the ERC crap
    [PCB KiCad.kicad_sch, adc.kicad_sch, led.kicad_sch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]
2022-03-09 Satisfy the overdemanding attention hungry ERC monster
    [PCB KiCad.kicad_sch, adc.kicad_sch, led.kicad_sch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]
2022-03-09 Add footprints
    [PCB KiCad.kicad_sch, adc.kicad_sch, led.kicad_sch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]
2022-03-09 Add board outline
    [PCB KiCad.kicad_pcb]
2022-03-09 start of component placement
    [PCB KiCad.kicad_pcb, PCB KiCad.kicad_sch, adc.kicad_sch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]
2022-03-09 Added missing footprint symbols
    [PCB KiCad.kicad_sch, adc.kicad_sch, mcu.kicad_sch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]
2022-03-09 placement of components
    [PCB KiCad.kicad_pcb, PCB KiCad.kicad_sch, mcu.kicad_sch]
2022-03-10 placement: working on the analog frontend
    [PCB KiCad.kicad_pcb]
2022-03-10 placement: rough layout done
    [PCB KiCad.kicad_pcb]
2022-03-10 routing: high-speed and sensitive signal routing done
    [PCB KiCad.kicad_pcb]
2022-03-10 routing: power pins connected
    [PCB KiCad.kicad_pcb]
2022-03-10 routing: fix J2 orientation (more intuitive)
    [PCB KiCad.kicad_pcb]
2022-03-11 routing: swap order of J1 ADC signals, swap buttons order
    [PCB KiCad.kicad_pcb, mcu.kicad_sch]
2022-03-11 routing: add ground plane, finish all tracks
    [PCB KiCad.kicad_pcb]
2022-03-14 silkscreen and thicker traces
    [PCB KiCad.kicad_pcb]
2022-03-15 Fixed mounting holes, added logo
    [PCB KiCad.kicad_pcb]
2022-03-15 export for review
    [PCB BOM.csv, PCB KiCad.kicad_sch, PCB KiCad.step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]
2022-03-16 update CAD files
    [PCB Front view.dxf, PCB KiCad.step]
2022-03-16 PCB at time of order
    [PCB KiCad.kicad_pcb, PCB KiCad.kicad_sch, PCB KiCad.step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]
2022-03-16 Delete PCB/PCB KiCad/PCB KiCad-backups directory
    show have been in gitignore
2022-04-04 fixes issue #09 and adds gnd testpad to make testing easier
    [PCB KiCad.kicad_pcb]
2022-04-04 adds gerber.zip file, because gitignore file was wrong
2022-04-11 Adds 1720nm datasheet and corrects some typ's
    [PCB KiCad.kicad_sch, adc.kicad_sch, led.kicad_sch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]
2022-05-10 adds PCB Pinout
2022-05-18 adds wavelengths to BOM
    [PCB BOM.csv, PCB KiCad.kicad_pcb, PCB KiCad.kicad_sch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]
2023-02-24 new datasheet 1720nm led
2023-02-27 adds correct values of current limiting resistors for LEDs
    [PCB KiCad.kicad_sch, led.kicad_sch]
2023-04-22 v2.2.0 first attempt for new ICs
    [Analog_Devices_-_ADR03ARZ-REEL7.step, Nuvoton_-_NAU7802SGI.step, OPA2376AID.step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]
2023-05-09 updated CAD
    [PCB Front view.dxf]
2023-05-09 update pcb
    [PCB KiCad-B_Cu.gbl, PCB KiCad-B_Mask.gbs, PCB KiCad-B_Silkscreen.gbo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]
2023-05-09 add pcb pinout pdf
2023-11-06 pre route
    [PCB KiCad.kicad_pcb, adc.kicad_sch, led.kicad_sch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]
2023-11-06 adds LP5951MFX
    [LP5951MFX-1.8_NOPB.step, PCB KiCad.kicad_pcb, adc.kicad_sch]
2023-11-09 square pcb
    [PCB KiCad.kicad_pcb]
2024-01-30 add 3D files
    [DB_enclosure_bottom.step, DB_enclosure_top.step, DB_enclosure_top_cover.step]
